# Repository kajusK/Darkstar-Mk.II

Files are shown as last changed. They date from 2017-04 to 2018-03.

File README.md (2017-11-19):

DarkStar Mk.II
==============

Small lightweight, water/mud/shock/bomb proof headlamp with bat roasting
light output and Scurion like body for 1/8 of the price. If you are caver,
mine explorer, biker, etc. with hacker soul, this is a way to go!

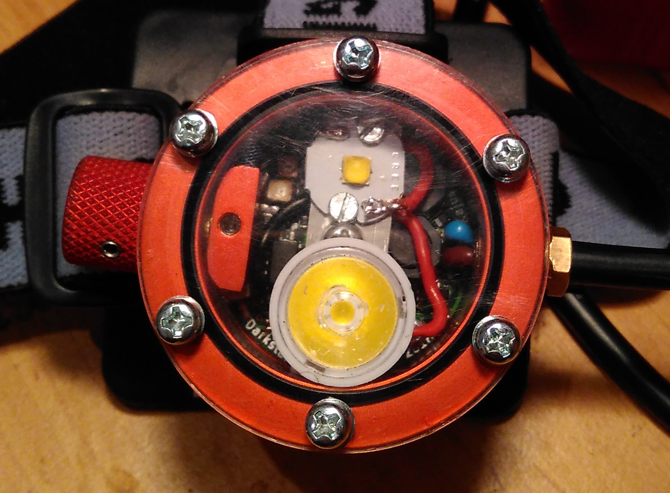
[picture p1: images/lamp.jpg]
Darkstar Mk.II


Features
--------
* Two high power high efficiency XP-L2 LEDs and two low power (e.g. red + UV).
* Up to 869 ANSI lumens (with 80 CRI 4000 K LEDs).
* Anodized aluminium alloy body.
* 3D printed battery box.
* Waterproof up to 2 (tested) meters (IPx8).
* 2 meter drop resistance tested
* Works in wide temperature range - minus 20 °C to plus 60 °C
* Custom high efficiency LED drivers - up to 96 %.
* Up to 2 Amps per LED.
* Runs on single Li-Ion cell, two are recommended for higher run times.
* Thoroughly tested - see [Measurements](./Measurements.md) for more details.
* Simple API for writing custom user modes.
* Temperature and voltage limits to avoid sudden power off or overheating.
* Long run time (over 30 days on lowest mode, over 1,5 hour on full power - for two 3400 mAh cells).
* Low power off current (27 uA), no need to unplug battery after use.
* Easily replaceable LEDs.
* Weights only 277 grams with two 18650 cells.
* Automated light control based on amount of reflected light (EXPERIMENTAL).
* Custom li-ion protection circuit - up to 7 Amps.

Submerged

Weight
------
* Lamp: 92 g
* Battery box: 50 g
* 2x18650 battery pack: 97 g
* Head strap: 38 g

HowTo
=====
Directories
-----------
* **avr** Source code and hex files for AVR
* **pcb** circuit diagrams, PCBs, gerber files and BOM for electrical parts
* **mechanical** Mechanical BOM, drawings, STLs

Electronics
-----------
The LED drivers were custom designed from elementary components, no integrated
LED solution was used. It's based on hystersis driven buck converter with current
feedback.

The current is sensed by 0,056 ohm resistor, voltage across this resistor is
amplified by opamp and fed to the comparator. The comparator is a brain of the
driver. When the measured voltage is higher than reference voltage generated by
MCU, comparator turns the MOSFET off, current drops below hystersis, MOSFET is turned on
and the cycle repeats. Nothing fancy, but quite simple and cheap.
Only few parts are required and measured efficiency is reaching 96 %. Over 90 \% for
currents over 0,5 A for whole supply voltage range allowed.
Check [Measurement](./Measurements.md) for more details.
The maximal current allowed is 2 Amps. It should be possible to get much higher
currents by choosing better (bigger and more expensice) inductors and transistors.

Disadvantage of such design is a limited lowest possible current, it can't go
below half of the hystersis current. For this reason 10-100 % output is constant
current driven, 0-10 % is controlled by additional PWM.

Software
--------

The brain of the lamp is Attiny 841, it handles key presses, reference voltage
generating, etc. To make it simpler to program I use optiboot arduino compatible
bootloader though there is no arduino code included in the project except
the bootloader itself.

To make it simpler to write your own control modes, most of the code is just a library
controlling the hardware and providing few quite low level functions to user. It
takes care of reading buttons, generating reference voltages for LED drivers, etc.

It also contains automated light control (PI regulator). The light is measured
by phototransistor and the difference between the measured value and value
required is run through the PI regulator. Result is the applied to reference
voltage generator. This feature is quite EXPERIMENTAL and doesn't work
well for caving when the lamps gets covered in mud.

The rest is the user mode. Check [simple mode](./avr/src/modes/simple.c) to see
how simple it can get. All relevant header are included. See [HowTo](./HowTo.md)
for more details on programming and stuff.

The caving mode controls are described in [User guide](./User_guide.md).

Mechanical
----------
The body is machined on a lathe from 6063 aluminium alloy. No fancy expensive
tools except lathe and drill press are required to make the lamp.

Top cover is made from polycarbonate sheet, cable and control rods bushings are
made from brass. The whole thing is sealed with O-rings. See the [BOM](./mechanical/BOM.md)
for more details.

The battery box is designed to be printed on any 3D printer. I would suggest
using ABS and painting the resulting print with ABS juice to get is as
waterproof as possible.

Lenses
------
the wide beam led can be used without lenses, the beam is wide enough for my
needs, for the narrow beam led you can buy any compatible lens that fits inside
the body. I used [17mm 10deg lens]
(http://www.aliexpress.com/item/free-shipping-cree-xp-g-lens-diameter-17mm-smooth-surface-with-stand-condenser-lenses-10-deg/777222733.html)

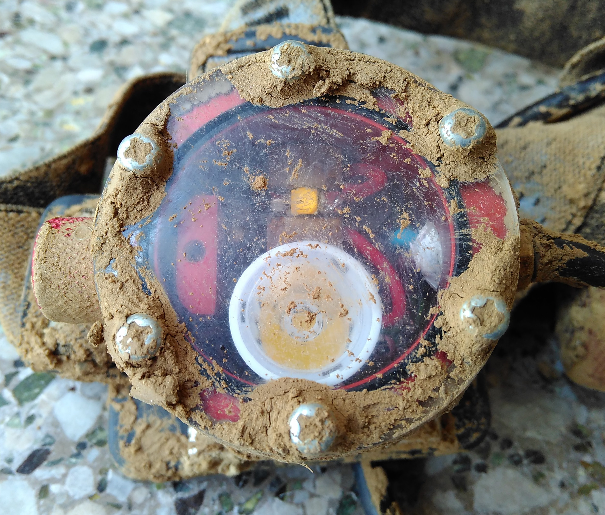
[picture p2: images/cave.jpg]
Cave usage


License
=======

The source code is licenced under [GNU GPL v2](./avr/LICENSE). The mechanical and
electrical design is licensed under [CERN OHL v.1.2](LICENSE).

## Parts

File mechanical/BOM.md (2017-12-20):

Bill Of Material
================

Mechanical only, for electronics see [headlamp BOM](../pcb/headlamp/BOM.csv)
and [li-ion protection BOM](../pcb/liion_protection/BOM.csv).

| Item					| Amount|
|---|---|
| Aluminium 6082 T6, rod, diameter 50	| 25 mm	|
| Aluminium 6082 T6, rod, diameter 15	| 45 mm	|
| Brass, hexagon rod, M11		| 20 mm	|
| Brass, hexagon rod, M8		| 20 mm	|
| Polycarbonate (lexan), 50x50x2 plate	| 1	|
| Screw M3x40, hex head			| 2	|
| Screw M3x5, phillips button head	| 7	|
| Screw M2x5, phillips button head	| 2	|
| Knurled nut M3 inserts		| 2	|
| Set screw M3x4			| 2	|
| O-ring 36x1,5				| 1	|
| O-ring 35x1,5				| 1	|
| O-ring 2x1,5				| 1	|
| Some ABS to print battery box		| 1	|
| 17mm condenser lens 10 deg for XP-L2	| 1	|

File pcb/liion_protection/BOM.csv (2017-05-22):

Reference | Value | Footprint | URL
Q2 | CSD16406Q3 | Housings_SON:VSON-8_3.3x3.3mm_Pitch0.65mm_NexFET | http://cz.mouser.com/search/ProductDetail.aspx?R=0virtualkey0virtualkeyCSD16406Q3
Q1 | CSD16406Q3 | Housings_SON:VSON-8_3.3x3.3mm_Pitch0.65mm_NexFET | http://cz.mouser.com/search/ProductDetail.aspx?R=0virtualkey0virtualkeyCSD16406Q3
R2 | 2k2 | Resistors_SMD:R_0603
R1 | 330R | Resistors_SMD:R_0603
C1 | 100n | Capacitors_SMD:C_0603
U1 | BQ29700DSER | Housings_SON:WSON6_1.5x1.5mm_Pitch0.5mm | http://cz.mouser.com/search/ProductDetail.aspx?R=0virtualkey0virtualkeyBQ29700DSER

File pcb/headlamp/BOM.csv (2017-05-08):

Reference | Value | Footprint | URL
C1 | 10u | Capacitors_SMD:C_0603
C10 | 10n | Capacitors_SMD:C_0603
C2 | 1u | Capacitors_SMD:C_0603
C4 | 1u | Capacitors_SMD:C_0603
C5 | 10n | Capacitors_SMD:C_0603
C6 | 1u | Capacitors_SMD:C_0603
C7 | 1u | Capacitors_SMD:C_0603
C8 | 1u | Capacitors_SMD:C_0603
C9 | 10n | Capacitors_SMD:C_0603
D2 | RED | LEDs:LED_PLCC-2 | http://cz.farnell.com/osram/lr-t67f-u1aa-1/led-smd-plcc2-red/dp/2113954
D3 | WHITE | LEDs:LED_PLCC-2 | http://cz.farnell.com/broadcom-limited/asmt-uwb1-nx3e2/led-smd-plcc2-neutral-white-4500k/dp/1895842
D4 | BAT60AE6327HTSA1 | Diodes_SMD:SOD-323 | http://cz.farnell.com/infineon/bat-60a-e6327/rectifier-schottky-3a-10v-sod/dp/2432679
D5 | BAT60AE6327HTSA1 | Diodes_SMD:SOD-323 | http://cz.farnell.com/infineon/bat-60a-e6327/rectifier-schottky-3a-10v-sod/dp/2432679
D6 | CREE XP-L2 |  | http://cz.mouser.com/ProductDetail/Cree-Inc/XPLBWT-00-0000-000HV340G/
D7 | CREE XP-L2 |  | http://cz.mouser.com/ProductDetail/Cree-Inc/XPLBWT-00-0000-000HV340G/
IC1 | ATTINY841-SSU | Housings_SOIC:SOIC-14_3.9x8.7mm_Pitch1.27mm | http://cz.farnell.com/atmel/attiny841-ssur/mcu-8bit-attiny-16mhz-wsoic-14/dp/2443189
L1 | 10u | Inductors:Inductor_Bourns-SRU8043 | http://cz.farnell.com/bourns/sru8043-100y/choke-power-shielded-10uh/dp/1362119
L2 | 10u | Inductors:Inductor_Bourns-SRU8043 | http://cz.farnell.com/bourns/sru8043-100y/choke-power-shielded-10uh/dp/1362119
Q1 | VEMT3700-GS08 | LEDs:LED_PLCC-2 | http://cz.farnell.com/vishay/vemt3700-gs08/photo-transistor-npn-850nm-plcc/dp/2504152
Q2 | NX2301P | TO_SOT_Packages_SMD:SOT-23 | http://cz.farnell.com/nxp/nx2301p/mosfet-p-ch-20v-2a-sot23/dp/1894738
Q3 | DMP2035U | TO_SOT_Packages_SMD:SOT-23 | http://cz.farnell.com/diodes-inc/dmp2035u/mosfet-p-ch-esd-20v-3-6a-sot23/dp/2061419
Q4 | DMP2035U | TO_SOT_Packages_SMD:SOT-23 | http://cz.farnell.com/diodes-inc/dmp2035u/mosfet-p-ch-esd-20v-3-6a-sot23/dp/2061419
R1 | 8k2 | Resistors_SMD:R_0603
R10 | 220R | Resistors_SMD:R_0603
R11 | 220R | Resistors_SMD:R_0603
R12 | 10k | Resistors_SMD:R_0603
R13 | 10k | Resistors_SMD:R_0603
R14 | 0R056 | Resistors_SMD:R_1206 | http://cz.farnell.com/te-connectivity/rlp73n2br056jtd/resistor-r056-300ppm-0-5w/dp/2116422
R15 | 0R056 | Resistors_SMD:R_1206 | http://cz.farnell.com/te-connectivity/rlp73n2br056jtd/resistor-r056-300ppm-0-5w/dp/2116422
R16 | 1k | Resistors_SMD:R_0603
R17 | 1k | Resistors_SMD:R_0603
R18 | 18k | Resistors_SMD:R_0603
R19 | 18k | Resistors_SMD:R_0603
R2 | 10k | Resistors_SMD:R_0603
R20 | 12k | Resistors_SMD:R_0603
R21 | 12k | Resistors_SMD:R_0603
R22 | 270k | Resistors_SMD:R_0603
R23 | 270k | Resistors_SMD:R_0603
R24 | 1k | Resistors_SMD:R_0603
R25 | 1k | Resistors_SMD:R_0603
R26 | 33R | Resistors_SMD:R_0603
R3 | 10k | Resistors_SMD:R_0603
R4 | 220R | Resistors_SMD:R_0603
R5 | 10k | Resistors_SMD:R_0603
R6 | 10k | Resistors_SMD:R_0603
R7 | 8k2 | Resistors_SMD:R_0603
R8 | 10k | Resistors_SMD:R_0603
R9 | 10k | Resistors_SMD:R_0603
SW1 | BT2 | Buttons_Switches_SMD:SW_SPST_FSMSM | http://cz.farnell.com/alcoswitch-te-connectivity/1437566-3/pushbutton-switch-spst-0-05a-24v/dp/2468741
SW2 | BT1 | Buttons_Switches_SMD:SW_SPST_FSMSM | http://cz.farnell.com/alcoswitch-te-connectivity/1437566-3/pushbutton-switch-spst-0-05a-24v/dp/2468741
U1 | ZXGD3001E6 | TO_SOT_Packages_SMD:SOT-23-6 | http://cz.farnell.com/diodes-inc/zxgd3001e6ta/driver-gate-bipolor-9a-peak/dp/1549138
U2 | ZXGD3001E6 | TO_SOT_Packages_SMD:SOT-23-6 | http://cz.farnell.com/diodes-inc/zxgd3001e6ta/driver-gate-bipolor-9a-peak/dp/1549138
U3 | TSV912 | Housings_SSOP:MSOP-8_3x3mm_Pitch0.65mm | http://cz.farnell.com/stmicroelectronics/tsv912aiyst/op-amp-rrio-8mhz-4-5v-s-8/dp/1842603
U4 | MCP6567 | Housings_SSOP:MSOP-8_3x3mm_Pitch0.65mm | http://cz.farnell.com/microchip/mcp6567-e-ms/ic-comparator-dual-1-8v-8msop/dp/1834862

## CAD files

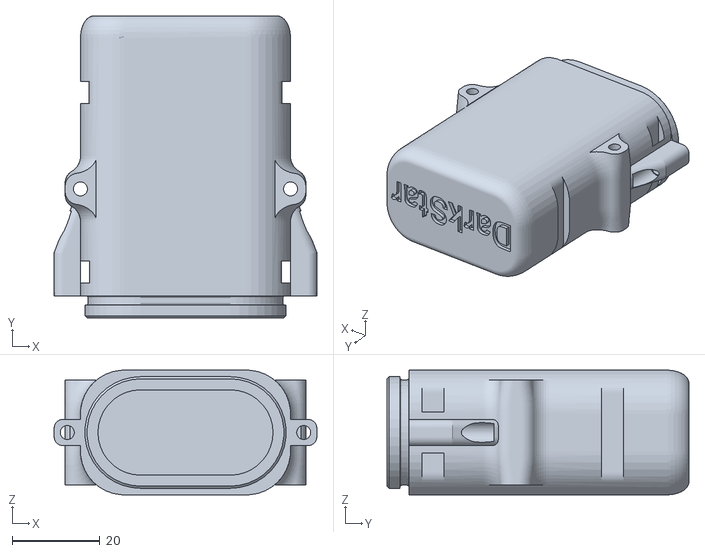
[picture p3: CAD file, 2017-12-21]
mechanical/stl/battery_box.stl
60.0 x 69.0 x 28.5

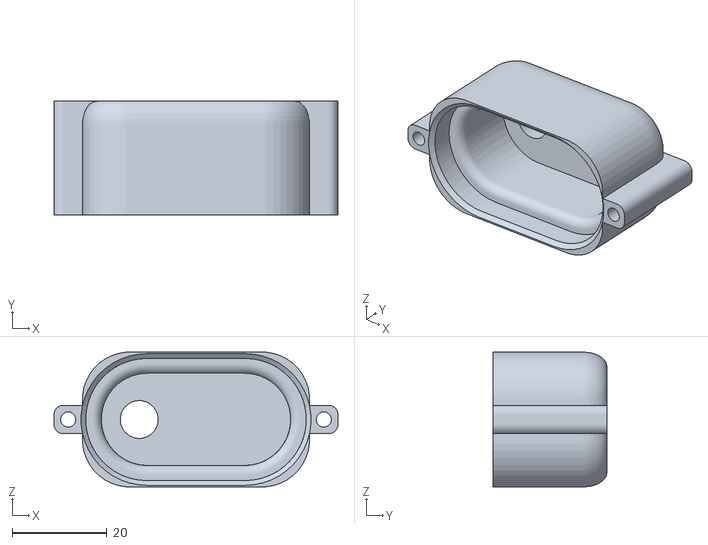
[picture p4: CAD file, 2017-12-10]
mechanical/stl/box_lid.stl
60.0 x 24.0 x 28.5

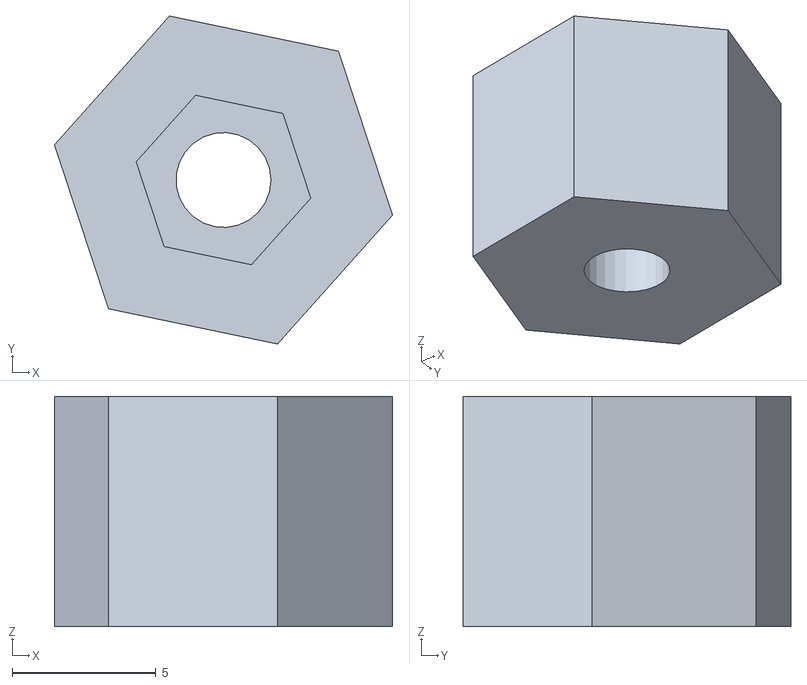
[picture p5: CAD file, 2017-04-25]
mechanical/stl/knob.stl
11.7 x 11.4 x 8.00

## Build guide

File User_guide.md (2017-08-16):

User guide
==========

Darkstar Mk.II light has four (one optional) sources of light:

- High power spot LED
- High power flood LED
- Low power red LED
- Low power white LED (optional)

The lamp is powered by 3,7 V Li-Ion rechargeable battery. Alternative power sources
are possible, voltage of such source must fall between 3 and 5 V.
Maximal worst condition current drawn is 4 A.

The lamp itself and battery box were designed for wet caves and harsh environment.
No drying is required after immersion in water. Cleaning can be done simply by
washing the whole lamp in water. Watertightness can be guaranteed only when
sealing O-rings are clean and lubricated properly though.

Programming
===========
There are two ways to update firmware. The hard one is using AVR ISP programmer,
soldering 6 wires to PCB (or using pogo pins). Simpler way is using bootloader
(if it was uploaded already). The darkstar Mk.II is using standard optiboot
bootloader compatible with arduino IDE.

See [HowTo](./HowTo.md).

Modes
=====
Caving firmware
---------------
While using caving mode firmware, the lamp can be in one of three modes:

- Normal
- Programming
- Configuration

### Normal mode

In normal mode, short button presses are changing brightness of all LEDs
based on the programmed levels. Long press of Down button while LEDs are
on will turn the headlamp off. If Up button is hold, programming mode is entered.
It's signalized by 1 blink.

If lamp is off and Down button is hold, the lock mode is activated. To disable
lock mode, just briefly push Up and Down buttons several times. If up button
is hold in off state, current battery level is reported by 1 (low) to 5 (full)
blinks.

Additionally, when the battery drops to ~50 %, it's signalized by one blink.
Low battery is 3 blinks. Something in the middle is signalized by 2 blinks. After
the blinking is finished, output power is limited by amount based on remaining
charge. Output power can be also limited when body temperature limit is reached.

### Programming mode

In this mode, current level selected can be changed for each LED. Up button
cycles SPOT LED levels, Down is for FLOOD. Holding Down toggles RED LED, holding
up toggles WHITE LED.

Programming mode is left automatically after 2,5 seconds of inactivity. Return
is followed by 1 slow blink.

### Configuration mode

Configuration mode is entered by holding Down button while connecting batteries.
Once in configuration mode, the red LED is on.

Up/Down buttons change number of modes available in normal mode. Long Down press
will blink out number of modes enabled.

Long Up press enables/disables programming mode. Enabled programming is confirmed by
two fast blinks. Disabled by one.

After the configuration is finished, wait for 2 seconds, disconnect the battery
and connect it again.

Simple firmware
---------------
Quite simple firmware with almost no features. It's more like technology
demonstration.

Holding DOWN button toggles RED LED. Holding UP button powers the headlamp
on and off. Short Up press cycles through spot LED power levels, Down press
changes flood LED output power.

There's no warning about battery state and heat/voltage limits are only for
the critical values (extra hot and almost dead battery). It won't let you in
the darkness immediately though, the hardcoded limits set output to minimum first.

Safety
======

- Always carry a second, independent source of light during your caving trip!

- Laser class 2 device. Do not look directly into the light.

- Keep the lamp and batteries away from children.

- Never short or mechanically damage the batteries, Li-Ion cell might catch fire or explode

- Never left batteries connected to charger without supervision

- When using alternate batteries, make sure the voltage applied and polarity is correct

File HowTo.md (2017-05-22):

Howto
=====

Writing custom mode
-------------------
When the mcu is powered on, it initializes itself and run init(). This function
has to be implemented in user mode and must return.

Then the infinite loop is entered. In the loop, library reads buttons, sets the
PWM generators, and runs loop() function from user mode. The loop() must return
withing 10ms and cannot be blocking.

For example how to write custom modes browse the [simple mode](./avr/src/modes/simple.c)
and api headers [system.h](./avr/src/library/system.h), [buttons.h](./avr/src/library/buttons.h)
and [light.h](./avr/src/library/light.h).

Compilation
-----------
To compile specific mode, just run

```
make MODE=modename
```

where modename is e.g. ***simple*** or ***caving***

MCU programming
---------------
Due to limited space, there is no dedicated programming connector on the PCB.
To burn the bootloader, you'll need program the MCU before soldering or
solder programmer wires directly to mcu pins or make custom programming head
using pogo pins.

The [optioboot](https://github.com/SpenceKonde/arduino-tiny-841/tree/master/avr/bootloaders/optiboot)
bootloader is recommended way to programm the MCU. The attiny841 has no boot
section, so the optiboot creates virtual boot partition by replacing
first instruction by jump to itself.

To make self programming working, SELFPRGEN fuse needs to be changed, e.g. by command:
```
avrdude -c usbtiny -p attiny841 -U efuse:w:0xFE:m
```

When the bootloader is burned, the MCU can be programmed over serial port.
When using serial interface, use supply voltage below 4 volts. On higher
voltages the internal oscillator runs faster and interferes with baudrate settings.
If you need to use UART on voltages over 4 volts, oscillator calibration might be
needed. The makefile contains programming target, just HW reset the MCU and run:

```
make MODE=modename program
```

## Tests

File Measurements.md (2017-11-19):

Measurements
============

Electrical and heat
-------------------
As the headlamp was build for my bachelor thesis, I went through couple of
measurements of various parameters.

The most important part is the LED driver. Its efficiency and heat management
defines most of the headlamp parameters.

When tested under maximum load - 4,2 V, 2 Amps - the drivers temperature
settles at 67 degrees Celsius.

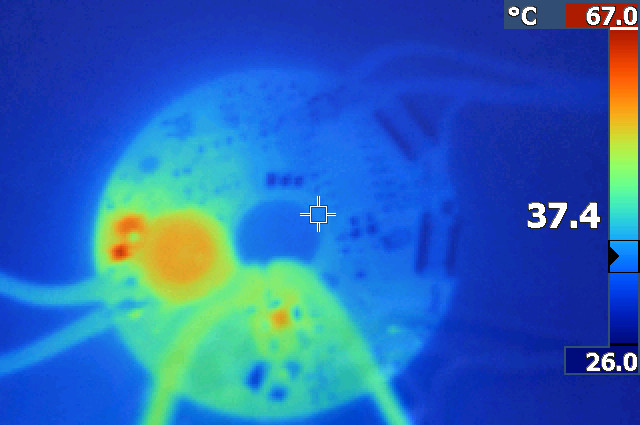
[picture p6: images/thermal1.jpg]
Driver heating


The measured efficiency is over 90 % for currents over 0,5 A over the whole
input voltage range and it's topping on 96,9 %.

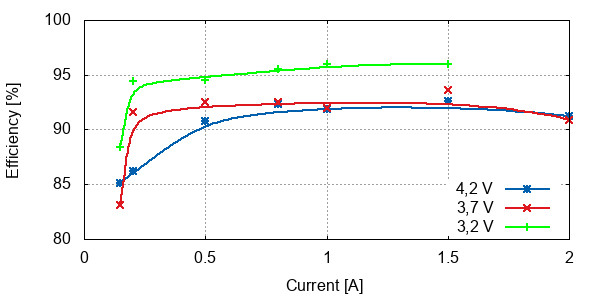
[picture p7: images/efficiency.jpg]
Efficiency


As the buck driver is hystersis driven, the frequency is not stable, but it varies
with input and output voltage significantly.

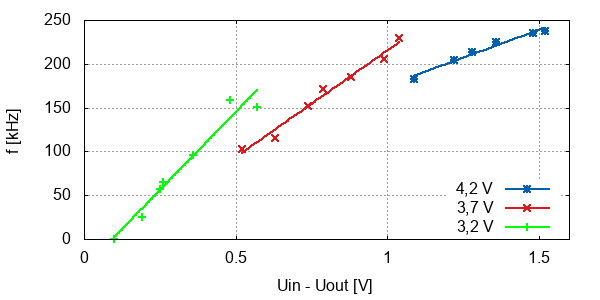
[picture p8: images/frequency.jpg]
Frequency


The driver supply voltage can go as low as 0,1 V over output voltage. 3,2 V battery
can therefore run XP-L2 on 2 Amps without any problem (when ignoring voltage drop
on wires).

As the comparator driving the switching transistor is open drain, there is non
zero current flowing through pull up and feedback resistor to ground when
the lamp is off. The measured power off current is 27 uA for the whole headlamp
with two drivers and MCU in sleep.

As the buck driver is in switching configuration, the current through LED is
not stable, but it's oscillating around the configured value with about
300 mA ripple.

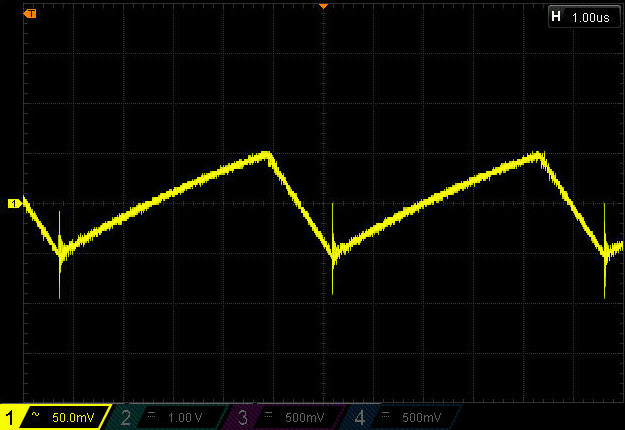
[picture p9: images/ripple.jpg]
Ripple


As there are no ideal components out there, the switching is not as smooth as
it could be. The diode recovery time is non zero and when the switch occurs,
voltage peak appears on the coil. The following image shows the issue (voltage
in the point where transistor, diode and inductor connect together).

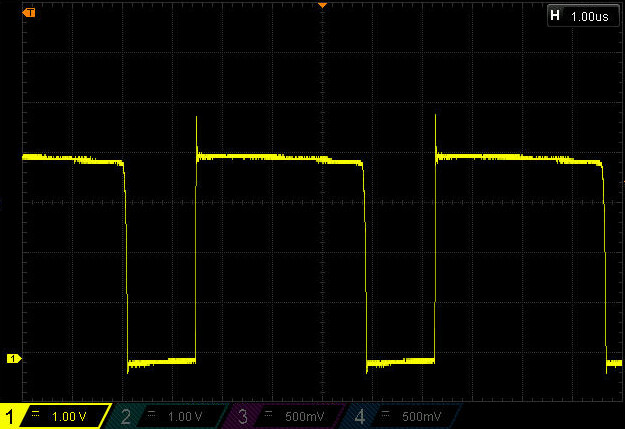
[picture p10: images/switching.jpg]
Switching


These peaks can get to the supply voltage. In the beginning I was using
diode detector to avoid voltage drops on MCU power rail, but the peaks
were slowly charging the capacitor on MCU side, voltage was rising. The result
was voltage break down of the opamp. After replacing the detector with RC
low pass, the problem was fixed.

When the lamp is running on full power, LEDs heat up to about 100 degree Celsius
before the body goes to 60 degrees and the temperature control kicks in.
This could be heavily improved by using cooper heatsink.

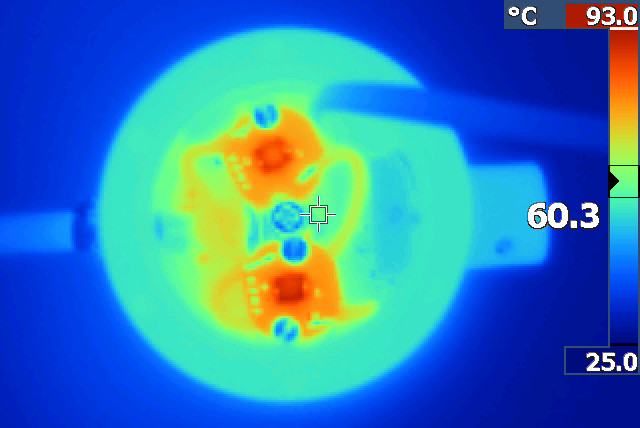
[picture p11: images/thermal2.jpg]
Body


Light
-----
The light was measured in integrating sphere at Faculty of Electrical Engineering
and Communication, Brno University of Technology.

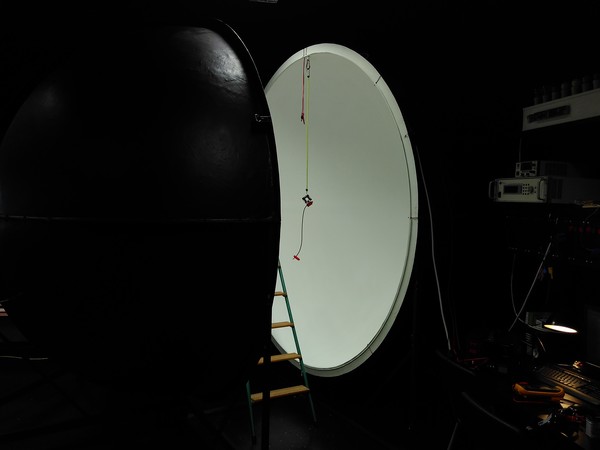
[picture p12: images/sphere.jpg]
Sphere


The measured light spectrum reveals a bit of LED principles. The peak at 450 nm
marks the light of the LED junction, the rest is created by luminophore.

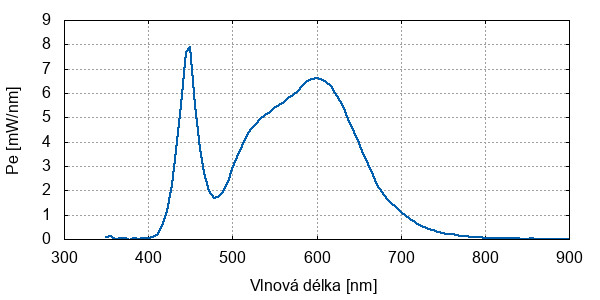
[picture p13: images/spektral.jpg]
Spektral


In the prototype measured, I used XP-L2, 4000K LEDs, one with CRI > 70, second
with CRI > 80.

| Item				| Value			|
|---|---|
| Min luminous flux		| 1,66 lm / 8 mA	|
| Max luminous flux		| 869 lm / 4 A		|
| Average max luminous flux	| 785 lm / 4 A		|
| Colour temperature		| 3937 K		|
| CRI				| 85,7			|

Temperature cycling
-------------------
To test the temperature range the lamp can work in, I put the lamp into the
freezer (-18 °C) for 30 minutes, checked everything works and then moved it into the oven
set to 60 degrees Celsius for 30 minutes and check if it works again.

This was repeated several times. The battery box got a bit soft in the oven.
The cable between the box and the lamp body was pretty hard after taking it out of the
freezer. But these changes were just temporary and everything else worked well.

Impact resistance
-----------------
The light was dropped from height 2 meters 6 times in different orientations on
a concrete floor. In the first set of tests, the optical part of the LED
was cut away by the lens, therefore I glued the lens into place and repeated
the test with a new LED. This time, nothing was damaged, only few scratches appeared
on the lamp surface.

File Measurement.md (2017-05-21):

Measurements
============

Electrical and heat
-------------------
As the headlamp was build for my bachelor thesis, I went through couple of
measurements of various parameters.

The most important part is the LED driver. Its efficiency and heat management
defines most of the headlamp parameters.

When tested under maximum load 4,2 V input, 2 amps load, the driver temperature
settles at 67 degrees Celsius.

Driver heating

The measured efficiency is over 90 % for currents over 0,5 A over the whole
input voltage range and it's topping on 96,9 %.

Efficiency

As the buck driver is hystersis driven, the frequency is not stable, but it varies
with input and output voltage significantly.

Frequency

The driver supply voltage can as low as 0,1 V over output voltage. 3,2 V battery
can therefore run XP-L2 on 2 Amps without any problem (when ignoring voltage drop
on wires).

As the comparator driving the switching transistor is open drain, there is non
zero current flowing through pull up and feedback resistor to ground when
the lamp is off. The measured power off current is 27 uA for the whole headlamp
with two drivers and MCU in sleep.

As the buck driver is in switching configuration, the current through LED is
not stable, but it's oscillating around the configured value with about
300 mA ripple.

Ripple

As there are no ideal components out there, the switching is not as smooth as
it could be. The diode recovery time is non zero and when the switch occurs,
voltage peak appears on the coil. The following image shows the issue (voltage
in the point where transistor, diode and coil connect together).

Switching

These peaks can get to the supply voltage, at the beginning I was using
diode detector to avoid voltage drops on MCU power rail, but the peaks
were slowly charging the capacitor on MCU side, voltage was rising. The result
was voltage break down of the opamp. After replacing the detector with RC
low pass, the problem was fixed.

When the lam is running on full power, LEDs heat up to about 100 degree Celsius
before the body goes to 60 degrees and the temperature control kicks in.
This could be heavily improved by using cooper heatsink.

Body

Light
-----
TODO

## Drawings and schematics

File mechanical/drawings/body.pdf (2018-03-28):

1 | 2 | 3 | 4
A | A

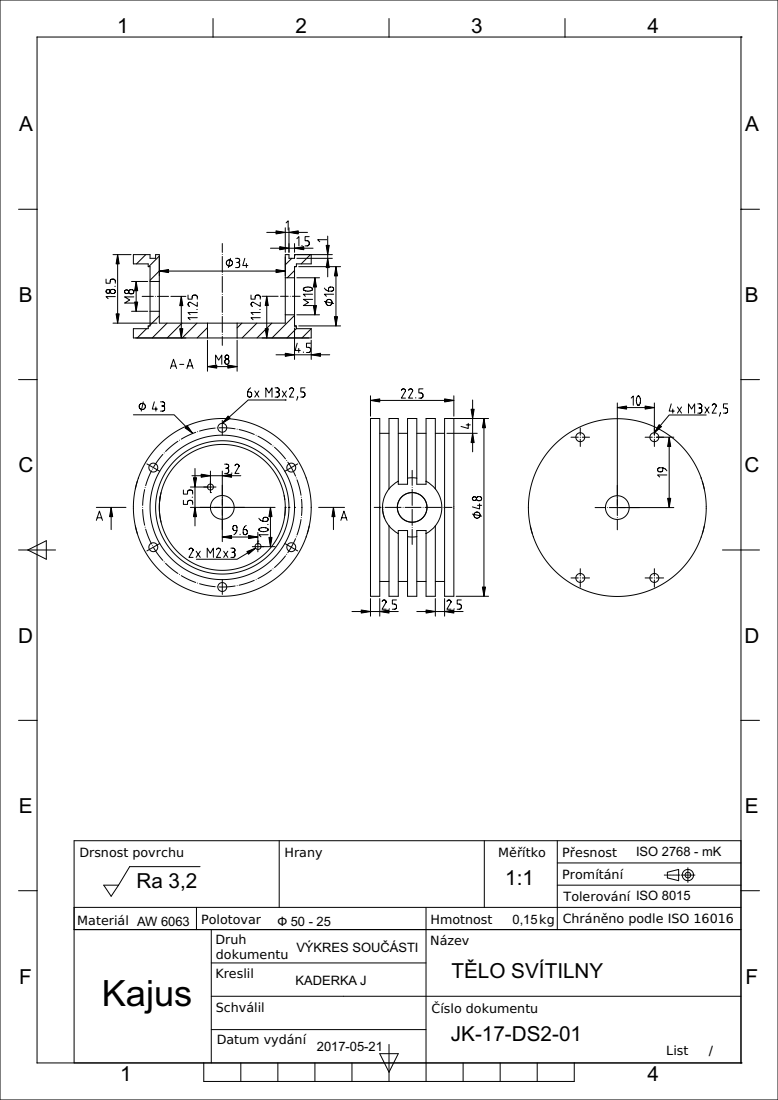
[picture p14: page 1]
Drsnost povrchu; Hrany; Kreslil; Měřítko; Přesnost; Tolerování; Promítání; KADERKA J; ISO 2768 - mK; ISO 8015

Materiál AW 6063 | Polotovar Ф 50 - 25 | Hmotnost 0,15 kg | Chráněno podle ISO 16016
Kajus | Druh VÝKRES SOUČÁSTI dokumentu | Název TĚLO SVÍTILNY

Schválil | Číslo dokumentu JK-17-DS2-01 List /

Datum vydání

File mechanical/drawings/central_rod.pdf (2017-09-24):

1 | 2 | 3 | 4
A | A

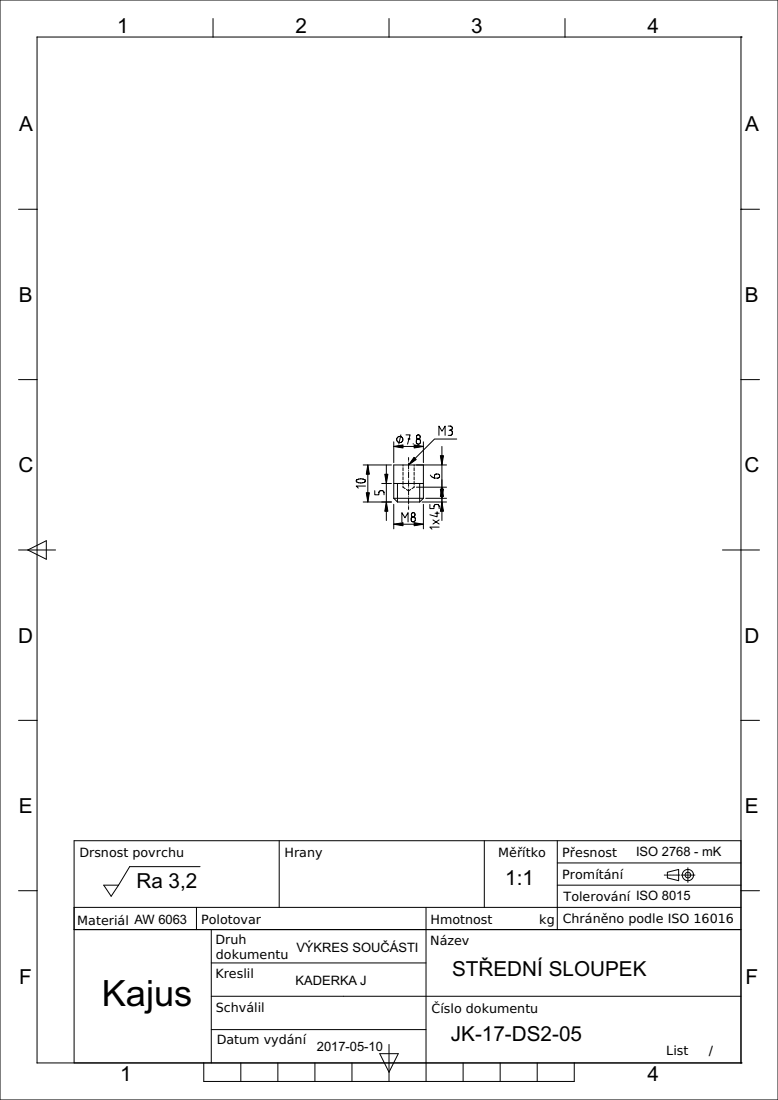
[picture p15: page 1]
Drsnost povrchu; Hrany; Kreslil; Měřítko; Přesnost; Tolerování; Promítání; KADERKA J; ISO 2768 - mK; ISO 8015

Materiál AW 6063 | Polotovar | Hmotnost kg | Chráněno podle ISO 16016
Kajus | Druh VÝKRES SOUČÁSTI dokumentu | Název STŘEDNÍ SLOUPEK

Schválil | Číslo dokumentu JK-17-DS2-05 List /

Datum vydání

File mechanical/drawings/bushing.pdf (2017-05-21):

1 | 2 | 3 | 4
A | A

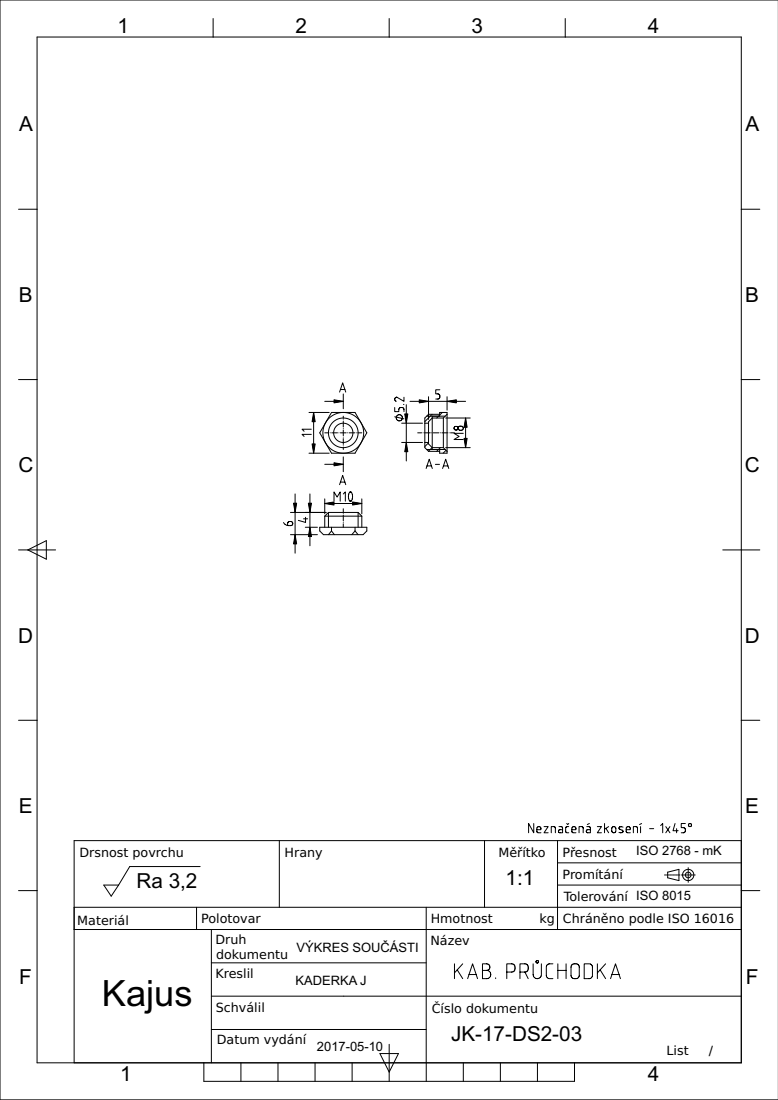
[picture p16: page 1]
Drsnost povrchu; Hrany; Kreslil; Měřítko; Přesnost; Tolerování; Promítání; KADERKA J; ISO 2768 - mK; ISO 8015

Materiál | Polotovar | Hmotnost kg | Chráněno podle ISO 16016
Kajus | Druh VÝKRES SOUČÁSTI dokumentu | Název

Schválil | Číslo dokumentu JK-17-DS2-03 List /

Datum vydání

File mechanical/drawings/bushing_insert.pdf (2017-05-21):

1 | 2 | 3 | 4
A | A

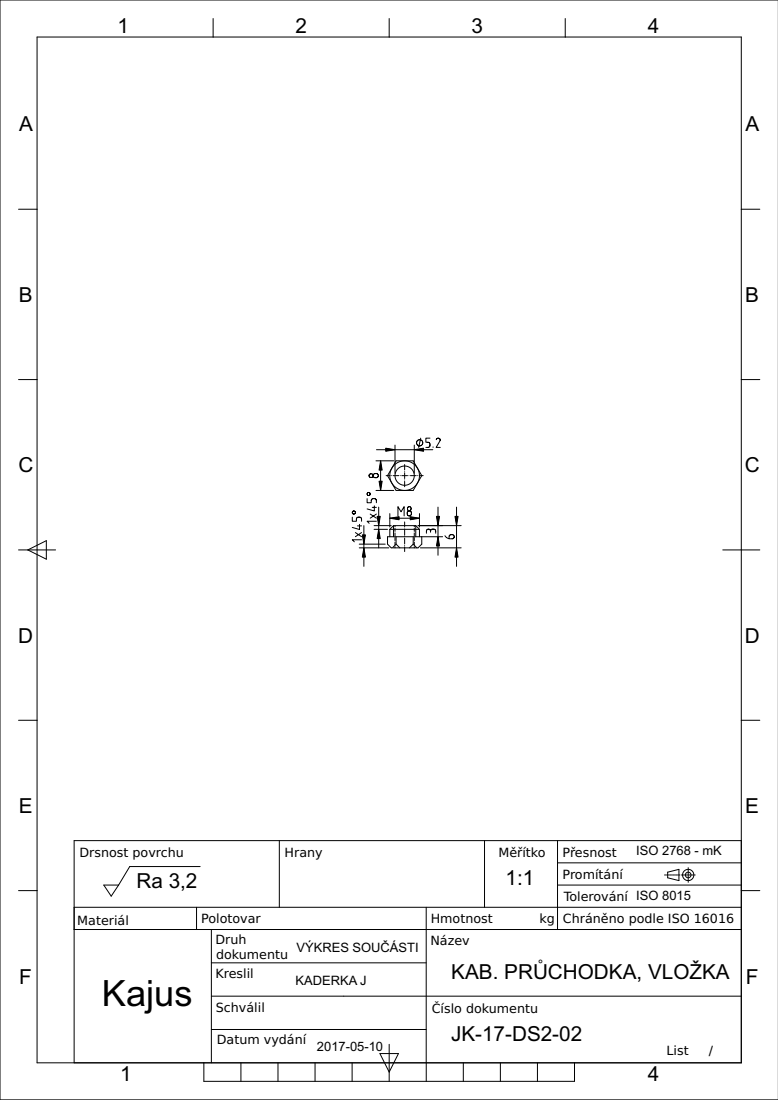
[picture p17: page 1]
Drsnost povrchu; Hrany; Kreslil; Měřítko; Přesnost; Tolerování; Promítání; KADERKA J; ISO 2768 - mK; ISO 8015

Materiál | Polotovar | Hmotnost kg | Chráněno podle ISO 16016
Kajus | Druh VÝKRES SOUČÁSTI dokumentu | Název KAB. PRŮCHODKA, VLOŽKA

Schválil | Číslo dokumentu JK-17-DS2-02 List /

Datum vydání

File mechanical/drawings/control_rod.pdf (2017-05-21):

1 | 2 | 3 | 4
A | A

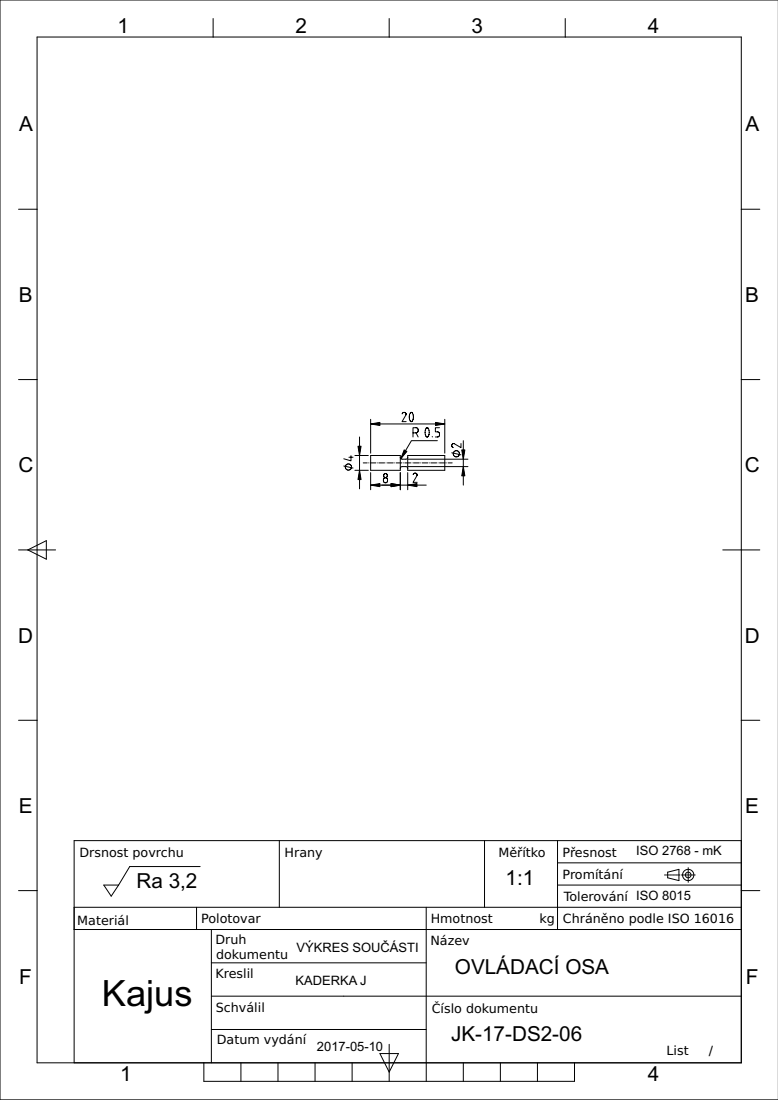
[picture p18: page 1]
Drsnost povrchu; Hrany; Kreslil; Měřítko; Přesnost; Tolerování; Promítání; KADERKA J; ISO 2768 - mK; ISO 8015

Materiál | Polotovar | Hmotnost kg | Chráněno podle ISO 16016
Kajus | Druh VÝKRES SOUČÁSTI dokumentu | Název OVLÁDACÍ OSA

Schválil | Číslo dokumentu JK-17-DS2-06 List /

Datum vydání

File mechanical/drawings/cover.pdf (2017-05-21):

1 | 2 | 3 | 4
A | A

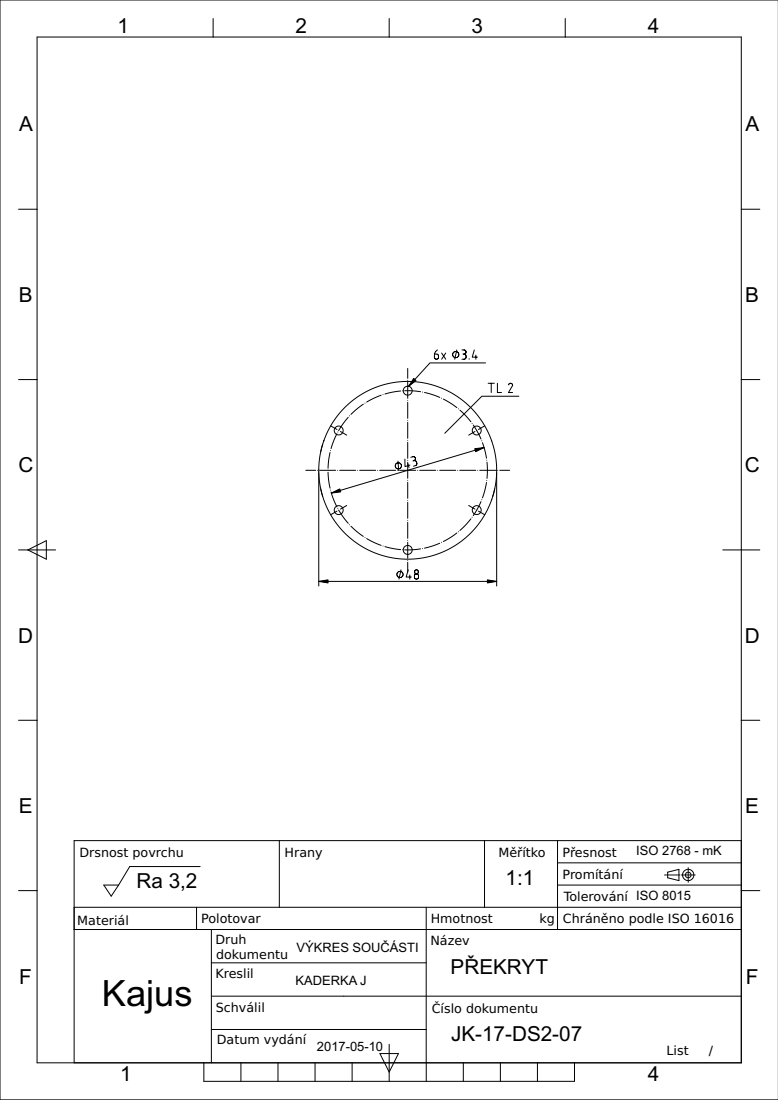
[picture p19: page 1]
Drsnost povrchu; Hrany; Kreslil; Měřítko; Přesnost; Tolerování; Promítání; KADERKA J; ISO 2768 - mK; ISO 8015

Materiál | Polotovar | Hmotnost kg | Chráněno podle ISO 16016
Kajus | Druh VÝKRES SOUČÁSTI dokumentu | Název PŘEKRYT

Schválil | Číslo dokumentu JK-17-DS2-07 List /

Datum vydání

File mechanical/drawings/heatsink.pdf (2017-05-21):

1 | 2 | 3 | 4
A | A

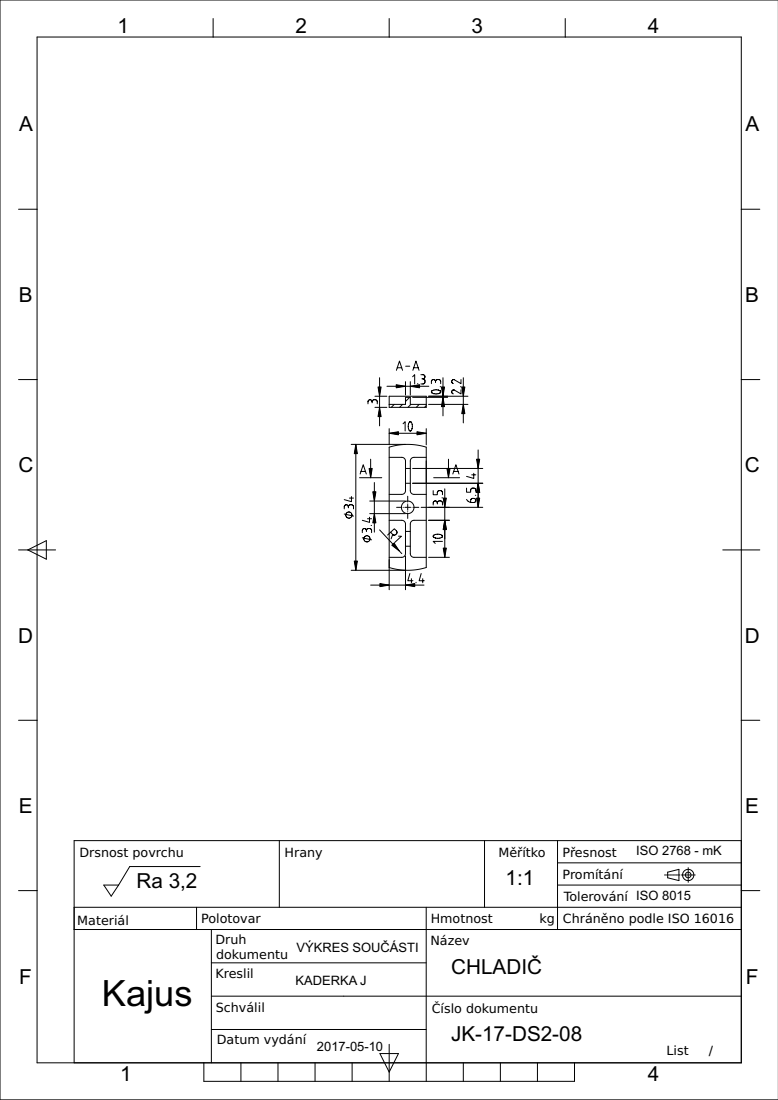
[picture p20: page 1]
Drsnost povrchu; Hrany; Kreslil; Měřítko; Přesnost; Tolerování; Promítání; KADERKA J; ISO 2768 - mK; ISO 8015

Materiál | Polotovar | Hmotnost kg | Chráněno podle ISO 16016
Kajus | Druh VÝKRES SOUČÁSTI dokumentu | Název CHLADIČ

Schválil | Číslo dokumentu JK-17-DS2-08 List /

Datum vydání

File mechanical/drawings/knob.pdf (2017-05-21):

1 | 2 | 3 | 4
A | A

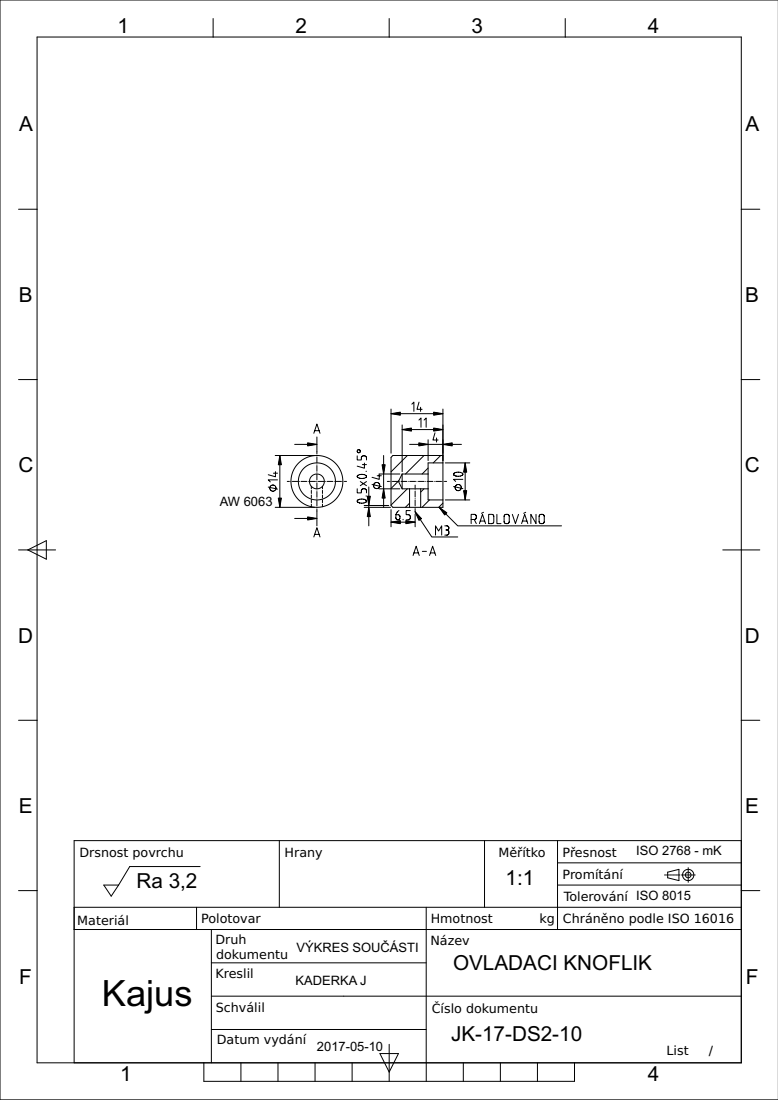
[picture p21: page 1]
Drsnost povrchu; Hrany; Kreslil; Měřítko; Přesnost; Tolerování; Promítání; KADERKA J; ISO 2768 - mK; ISO 8015

Materiál | Polotovar | Hmotnost kg | Chráněno podle ISO 16016
Kajus | Druh VÝKRES SOUČÁSTI dokumentu | Název OVLADACI KNOFLIK

Schválil | Číslo dokumentu JK-17-DS2-10 List /

Datum vydání

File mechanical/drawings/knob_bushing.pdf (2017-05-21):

1 | 2 | 3 | 4
A | A

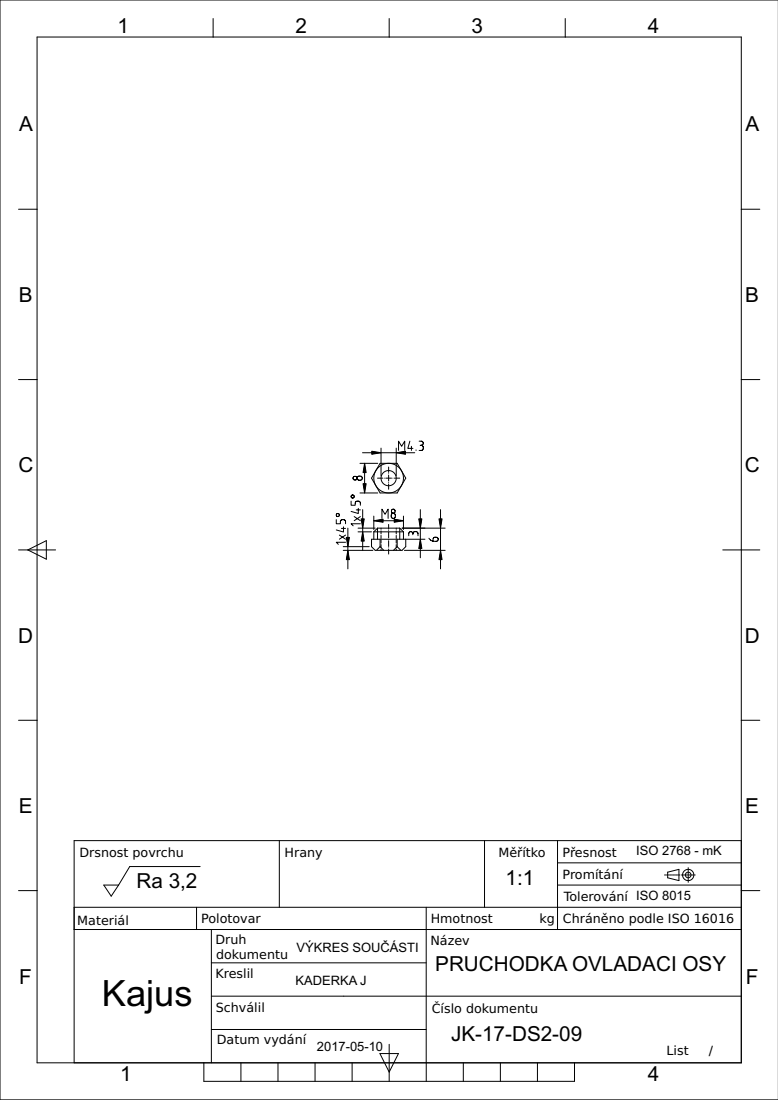
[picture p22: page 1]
Drsnost povrchu; Hrany; Kreslil; Měřítko; Přesnost; Tolerování; Promítání; KADERKA J; ISO 2768 - mK; ISO 8015

Materiál | Polotovar | Hmotnost kg | Chráněno podle ISO 16016
Kajus | Druh VÝKRES SOUČÁSTI dokumentu | Název PRUCHODKA OVLADACI OSY

Schválil | Číslo dokumentu JK-17-DS2-09 List /

Datum vydání

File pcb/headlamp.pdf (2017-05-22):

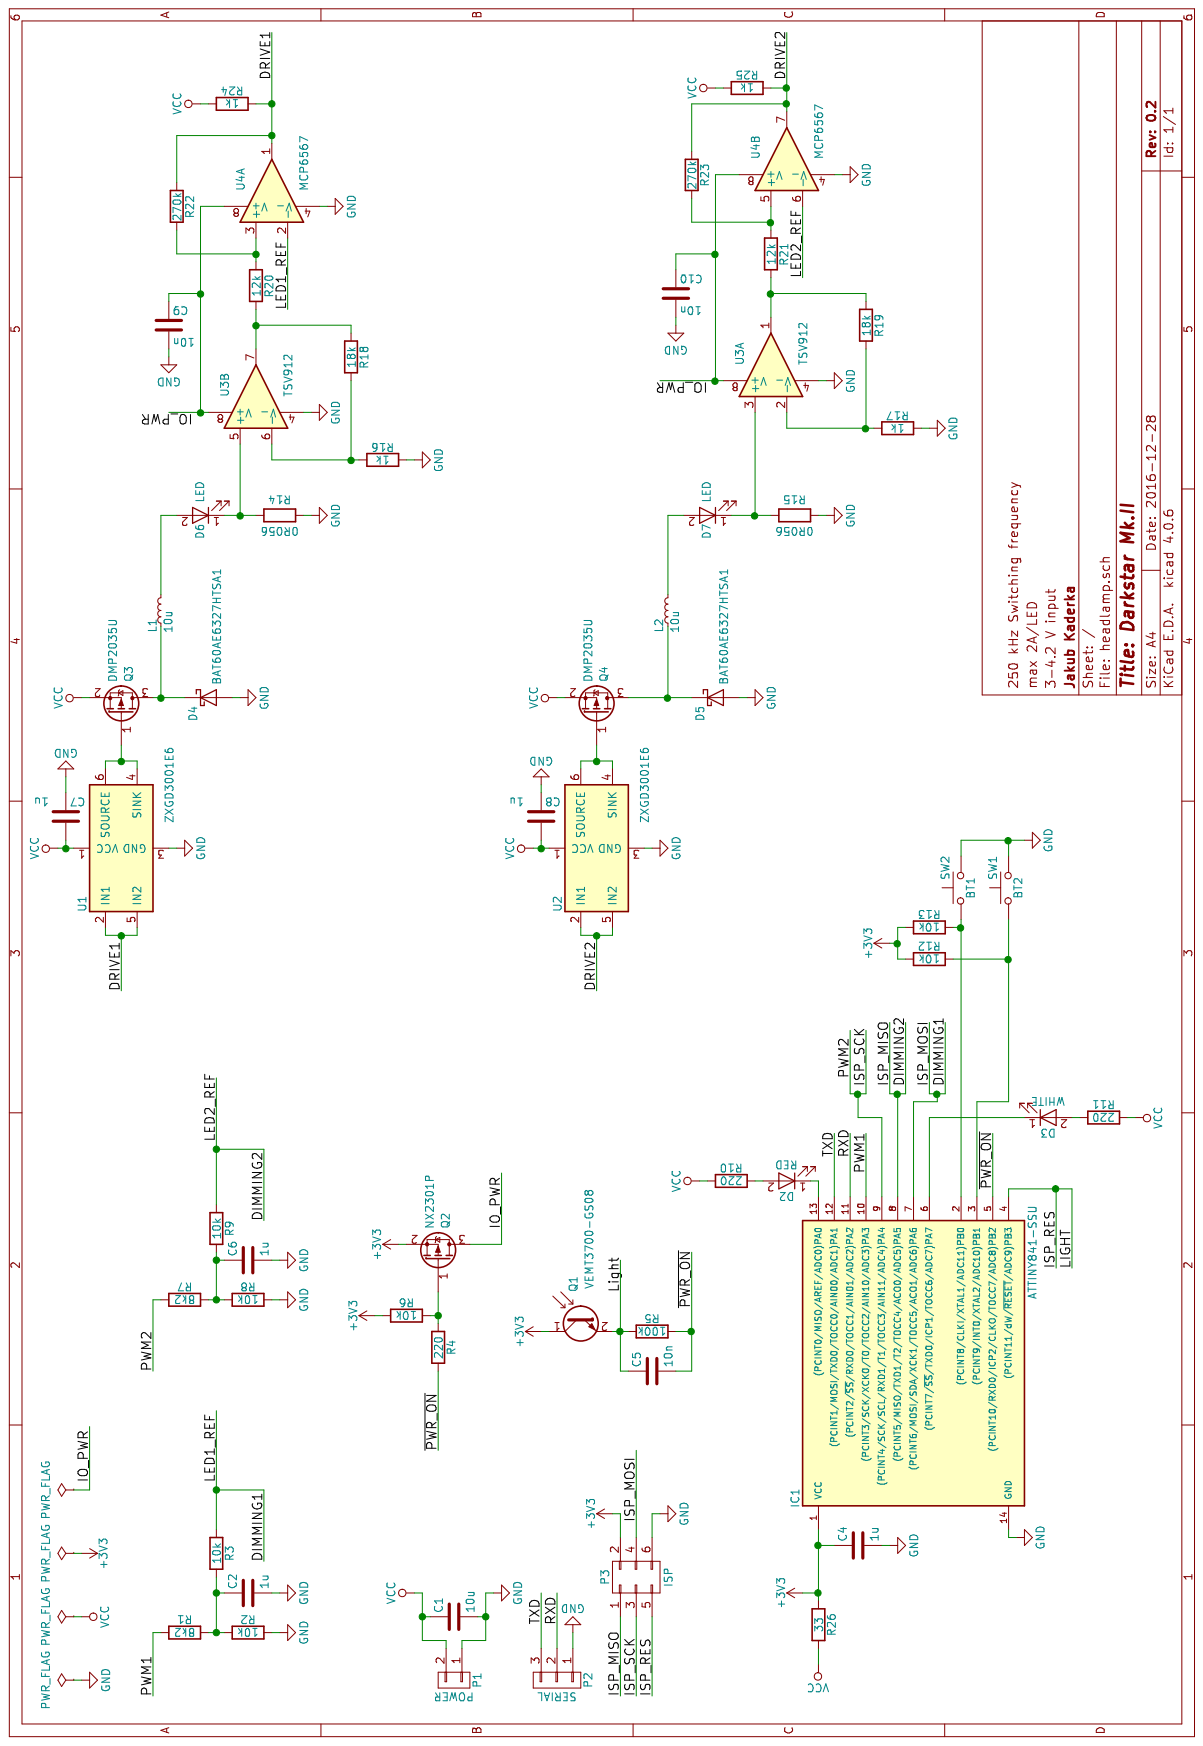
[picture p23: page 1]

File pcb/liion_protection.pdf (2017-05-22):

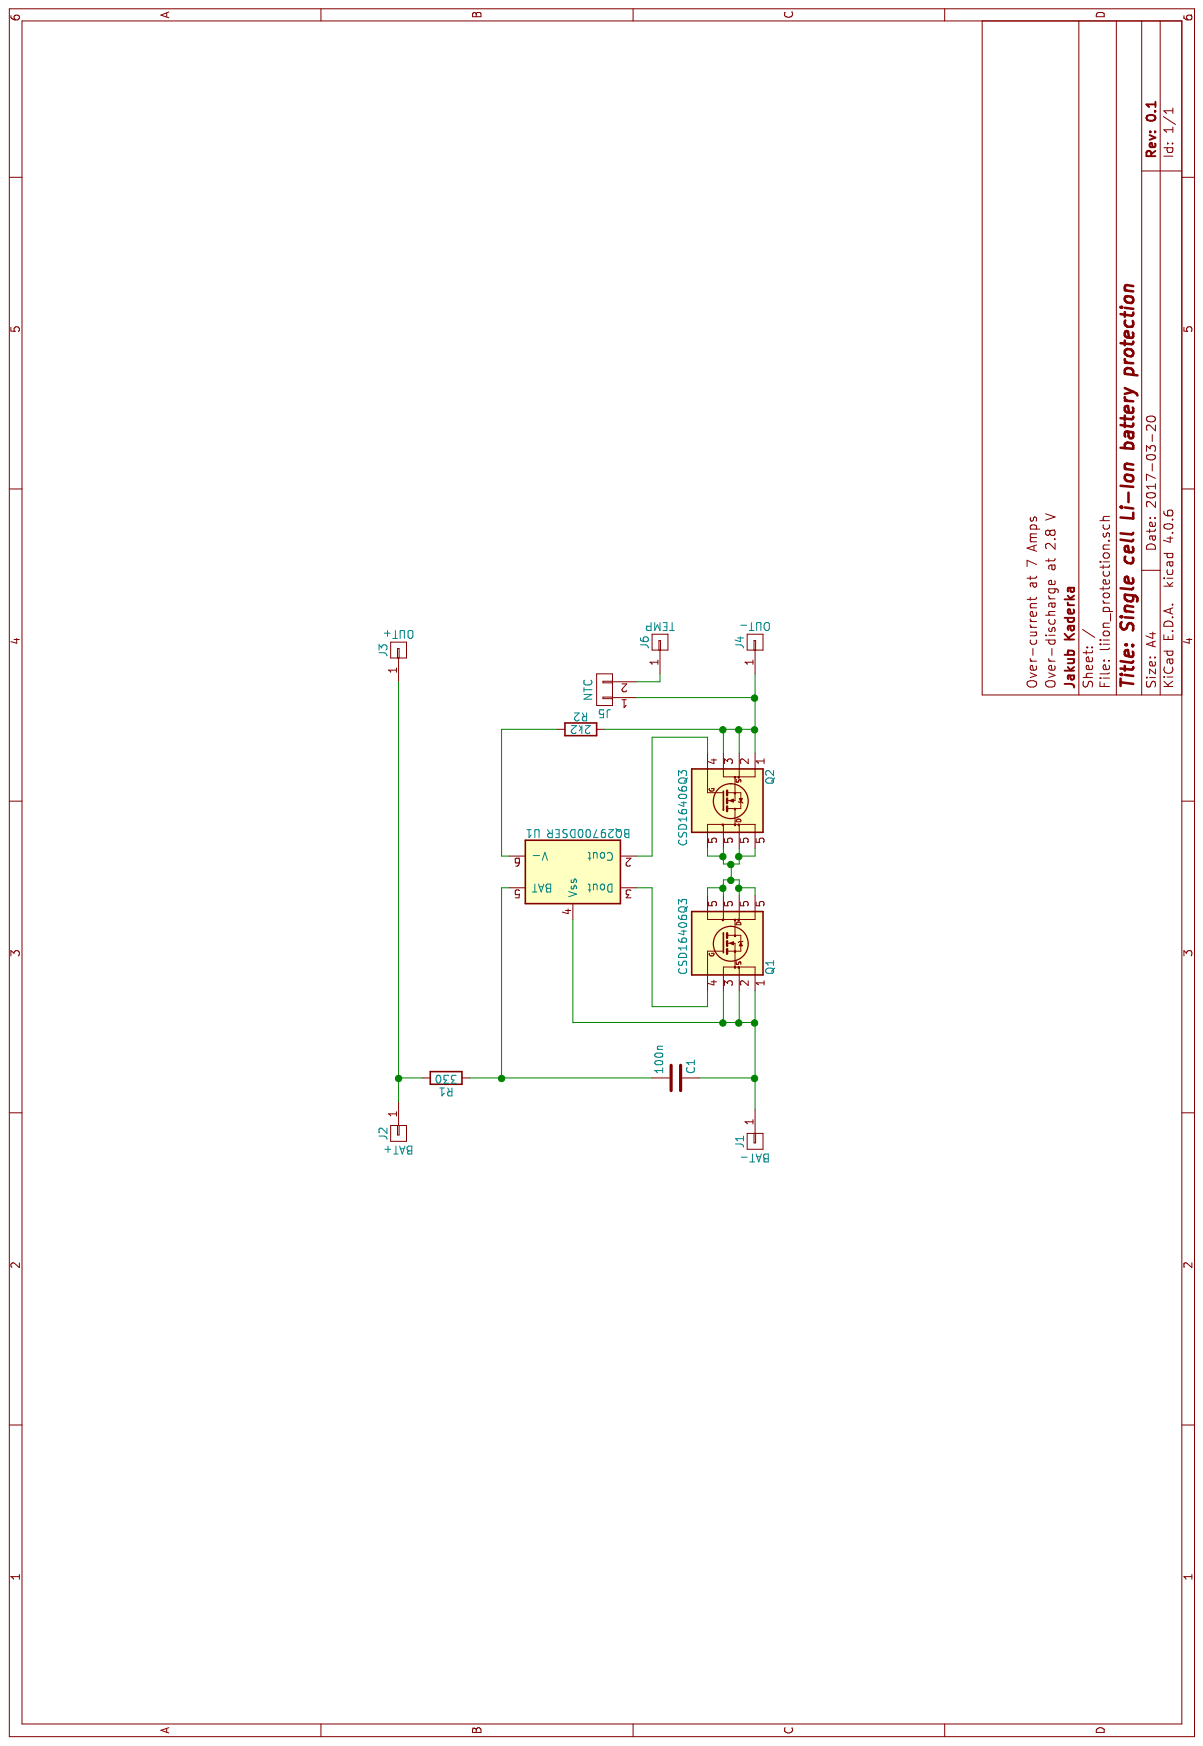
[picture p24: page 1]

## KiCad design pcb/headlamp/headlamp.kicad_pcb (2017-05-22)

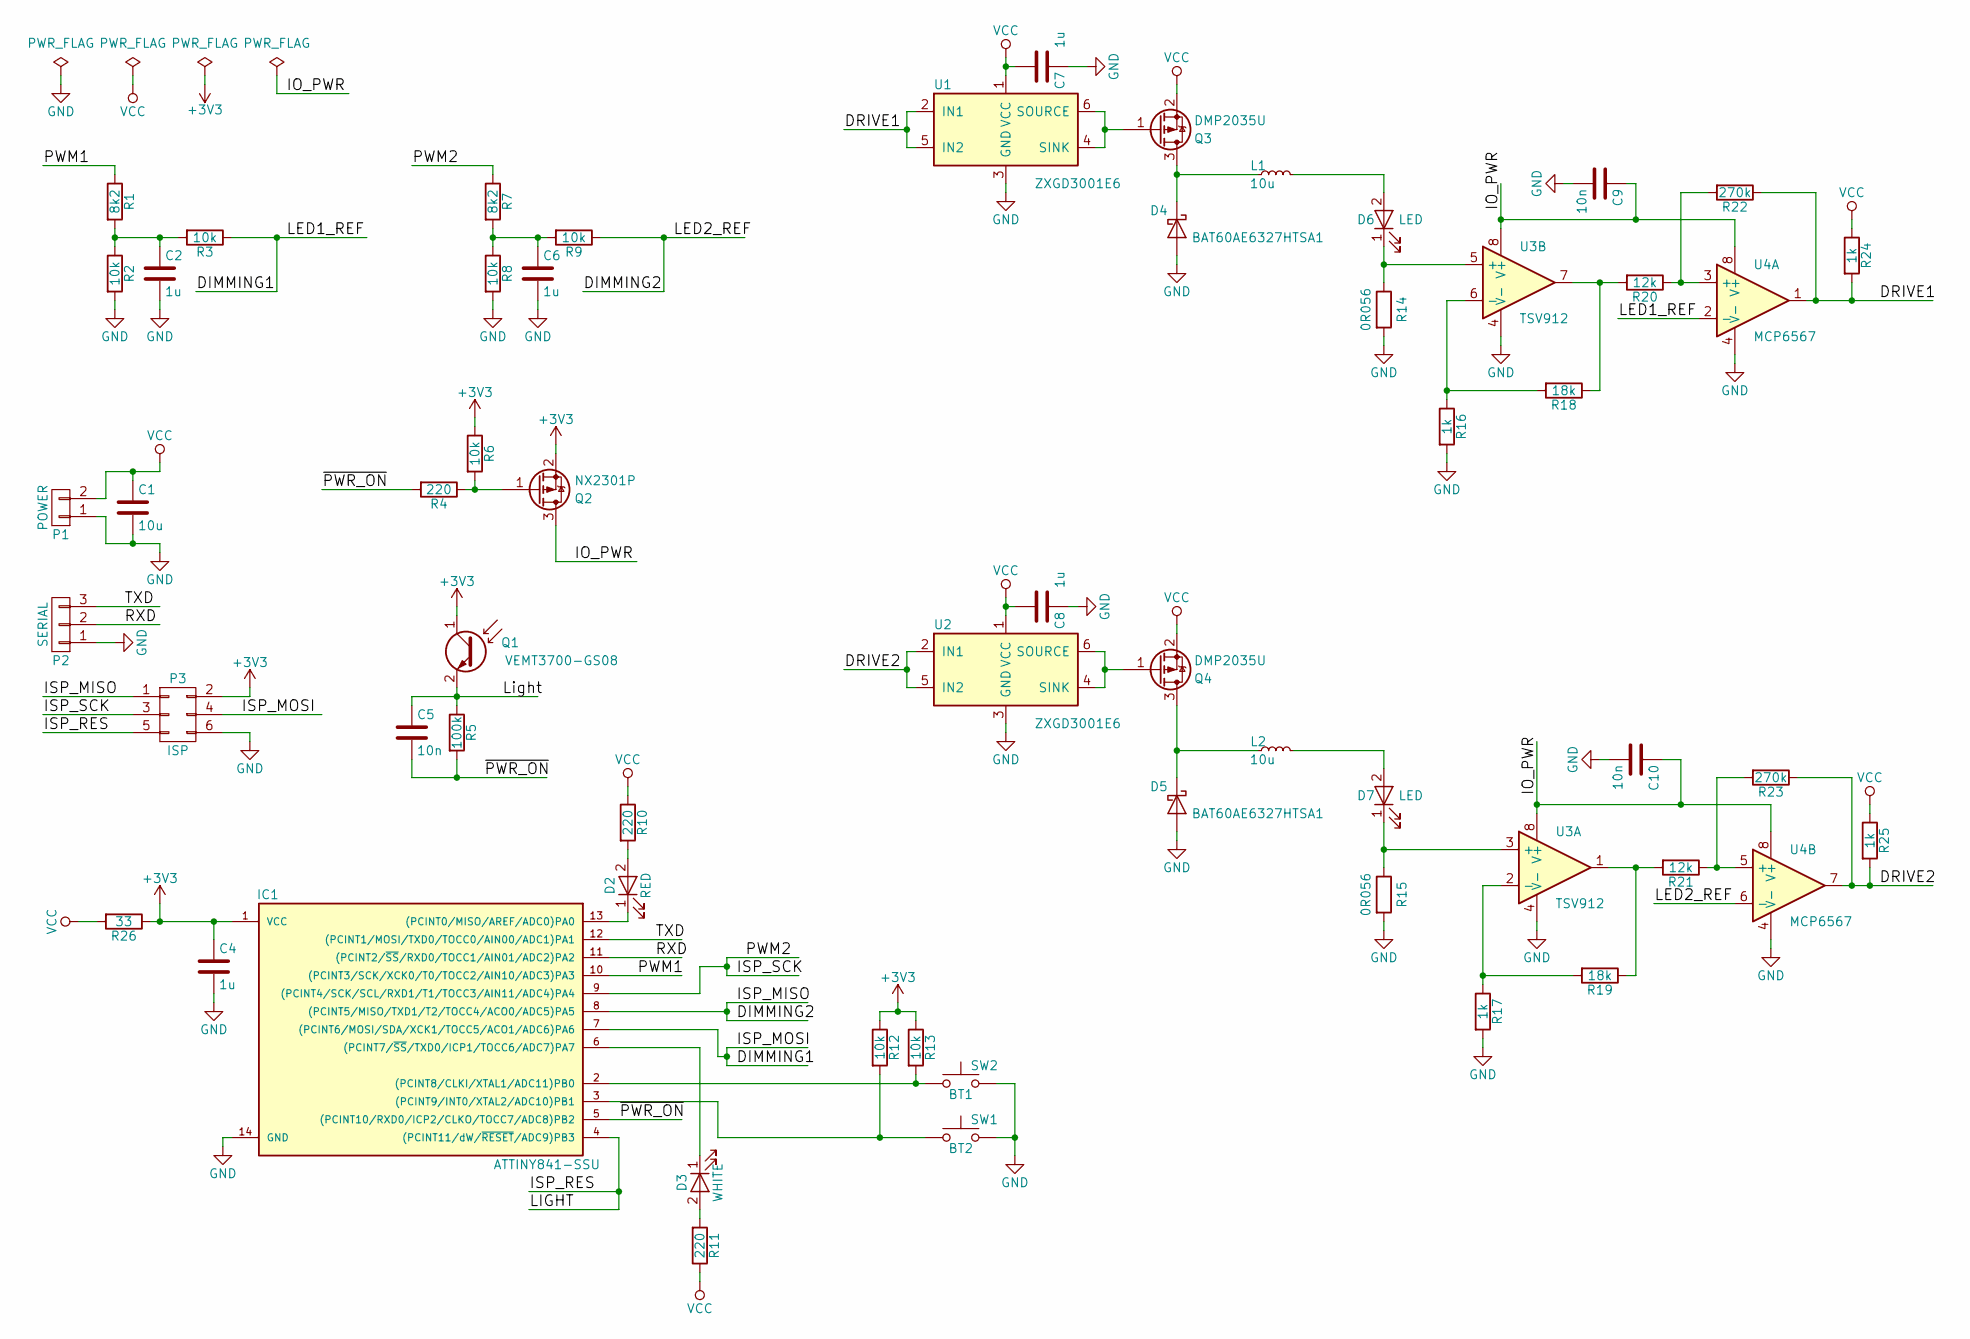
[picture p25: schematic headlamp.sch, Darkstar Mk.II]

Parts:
C1: 10u; C_0603
C2, C4, C6, C7, C8: 1u; C_0603
C5, C9, C10: 10n; C_0603
D2: RED; LED_PLCC-2
D3: WHITE; LED_PLCC-2
D4, D5: BAT60AE6327HTSA1; SOD-323
D6, D7: LED; Custom_Conn_2_Big
IC1: ATTINY841-SSU; SOIC-14_3.9x8.7mm_Pitch1.27mm
L1, L2: 10u; Inductor_Bourns-SRU8043
P1: POWER; Custom_Conn_2_Big
P2: SERIAL; GS3
P3: ISP; SOT-23-6
Q1: VEMT3700-GS08; LED_PLCC-2
Q2: NX2301P; SOT-23
Q3, Q4: DMP2035U; SOT-23
R1, R7: 8k2; R_0603
R2, R3, R6, R8, R9, R12, R13: 10k; R_0603
R4, R10, R11: 220; R_0603
R5: 100k; R_0603
R14, R15: 0R056; R_1206
R16, R17, R24, R25: 1k; R_0603
R18, R19: 18k; R_0603
R20, R21: 12k; R_0603
R22, R23: 270k; R_0603
R26: 33; R_0603
SW1: BT2; SW_SPST_FSMSM
SW2: BT1; SW_SPST_FSMSM
U1, U2: ZXGD3001E6; SOT-23-6
U3: TSV912; MSOP-8_3x3mm_Pitch0.65mm
U4: MCP6567; MSOP-8_3x3mm_Pitch0.65mm

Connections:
+3V3: C4.1, IC1.1 (VCC), P3.2, Q1.1 (C), Q2.2 (S), R6.1, R12.1, R13.1, R26.1
/DIMMING1: IC1.7 ((PCINT6/MOSI/SDA/XCK1/TOCC5/ACO1/ADC6)P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), P3.4, R3.1, U4.2 (-)
/DIMMING2: IC1.8 ((PCINT5/MISO/TXD1/T2/TOCC4/ACO0/ADC5)PA5), P3.1, R9.1, U4.6 (-)
/DRIVE1: R22.1, R24.2, U1.2 (IN1), U1.5 (IN2), U4.1
/DRIVE2: R23.1, R25.2, U2.2 (IN1), U2.5 (IN2), U4.7
/IO_PWR: C9.1, C10.1, Q2.3 (D), U3.8 (V+), U4.8 (V+)
/ISP_RES: C5.1, IC1.4 ((PCINT11/dW/~RESET~/ADC9)PB3), P3.5, Q1.2 (E), R5.1
/ISP_SCK: IC1.9 ((PCINT4/SCK/SCL/RXD1/T1/TOCC3/AIN11/ADC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), P3.3, R7.1
/PWM1: IC1.10 ((PCINT3/SCK/XCK0/T0/TOCC2/AIN10/ADC3)PA3), R1.1
/RXD: IC1.11 ((PCINT2/~SS~/RXD0/TOCC1/AIN01/ADC2)PA2), P2.2
/TXD: IC1.12 ((PCINT1/MOSI/TXD0/TOCC0/AIN00/ADC1)PA1), P2.3
/~PWR_ON: C5.2, IC1.5 ((PCINT10/RXD0/ICP2/CLKO/TOCC7/ADC8)PB2), R4.2, R5.2
GND: C1.2, C2.2, C4.2, C6.2, C7.1, C8.1, C9.2, C10.2, D4.2 (A), D5.2 (A), IC1.14 (GND), P1.1, P2.1, P3.6, R2.2, R8.2, R14.2, R15.2, R16.2, R17.2, SW1.2, SW2.2, U1.3 (GND), U2.3 (GND), U3.4 (V-), U4.4 (V-)
unnamed: C2.1, R1.2, R2.1, R3.2
unnamed: C6.1, R7.2, R8.1, R9.2
unnamed: D2.1 (K), IC1.13 ((PCINT0/MISO/AREF/ADC0)PA0)
unnamed: D2.2 (A), R10.2
unnamed: D3.1 (K), IC1.6 ((PCINT7/~SS~/TXD0/ICP1/TOCC6/ADC7)PA7)
unnamed: D3.2 (A), R11.2
unnamed: D4.1 (K), L1.1, Q3.3 (D)
unnamed: D5.1 (K), L2.1, Q4.3 (D)
unnamed: D6.1 (K), R14.1, U3.5 (+)
unnamed: D6.2 (A), L1.2
unnamed: D7.1 (K), R15.1, U3.3 (+)
unnamed: D7.2 (A), L2.2
unnamed: IC1.2 ((PCINT8/CLKI/XTAL1/ADC11)PB0), R13.2, SW2.1
unnamed: IC1.3 ((PCINT9/INT0/XTAL2/ADC10)PB1), R12.2, SW1.1
unnamed: Q2.1 (G), R4.1, R6.2
unnamed: Q3.1 (G), U1.4 (SINK), U1.6 (SOURCE)
unnamed: Q4.1 (G), U2.4 (SINK), U2.6 (SOURCE)
unnamed: R16.1, R18.2, U3.6 (-)
unnamed: R17.1, R19.2, U3.2 (-)
unnamed: R18.1, R20.2, U3.7
unnamed: R19.1, R21.2, U3.1
unnamed: R20.1, R22.2, U4.3 (+)
unnamed: R21.1, R23.2, U4.5 (+)
VCC: C1.1, C7.2, C8.2, P1.2, Q3.2 (S), Q4.2 (S), R10.1, R11.1, R24.1, R25.1, R26.2, U1.1 (VCC), U2.1 (VCC)

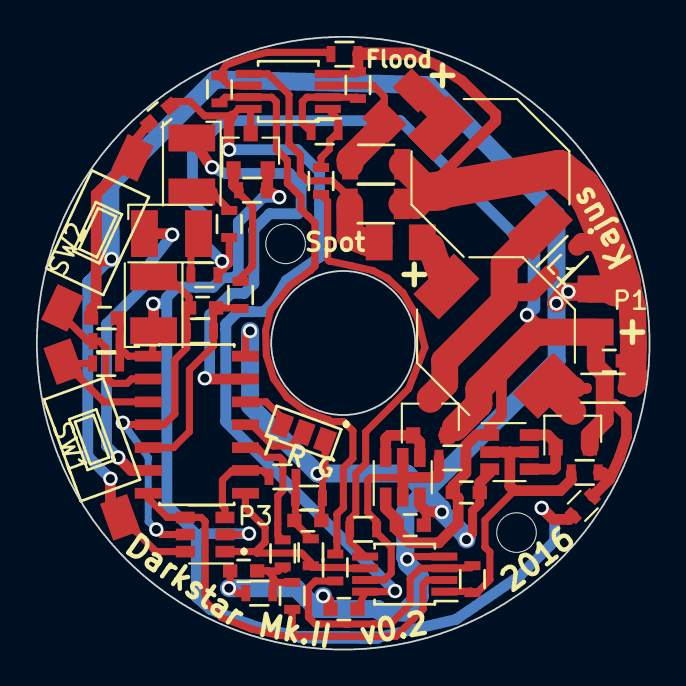
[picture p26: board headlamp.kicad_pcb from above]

Board: 2 copper layers, 34.0 x 34.0 mm, 57 parts (0 on the bottom side), 37 nets.

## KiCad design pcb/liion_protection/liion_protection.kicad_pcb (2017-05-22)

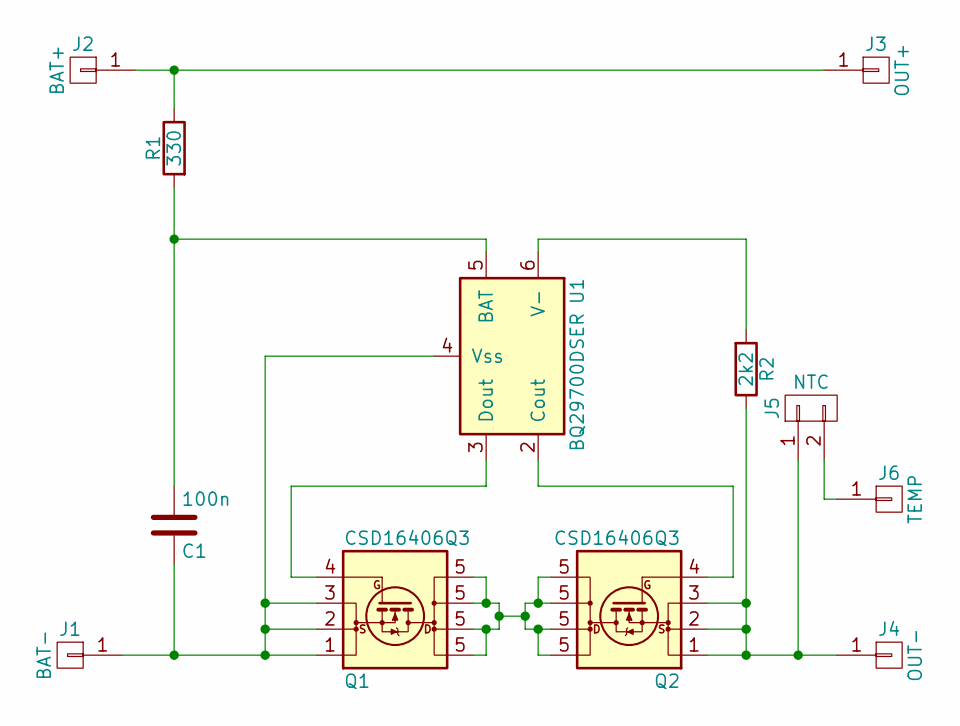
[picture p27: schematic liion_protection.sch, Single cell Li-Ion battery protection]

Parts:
C1: 100n; C_0603
J1: BAT-; 1Pin
J2: BAT+; 1Pin
J3: OUT+; 1Pin
J4: OUT-; 1Pin
J5: NTC; GS2
J6: TEMP; 1Pin
Q1, Q2: CSD16406Q3; VSON-8_3.3x3.3mm_Pitch0.65mm_NexFET
R1: 330; R_0603
R2: 2k2; R_0603
U1: BQ29700DSER; WSON6_1.5x1.5mm_Pitch0.5mm

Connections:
unnamed: C1.1, J1.1, Q1.1 (S), Q1.2 (S), Q1.3 (S), U1.4 (Vss)
unnamed: C1.2, R1.2, U1.5 (BAT)
unnamed: J2.1, J3.1, R1.1
unnamed: J4.1, J5.1, Q2.1 (S), Q2.2 (S), Q2.3 (S), R2.1
unnamed: J5.2, J6.1
unnamed: Q1.4 (G), U1.3 (Dout)
unnamed: Q1.5 (D), Q2.5 (D)
unnamed: Q2.4 (G), U1.2 (Cout)
unnamed: R2.2, U1.6 (V-)

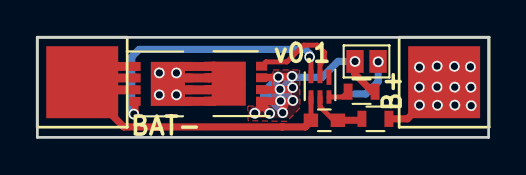
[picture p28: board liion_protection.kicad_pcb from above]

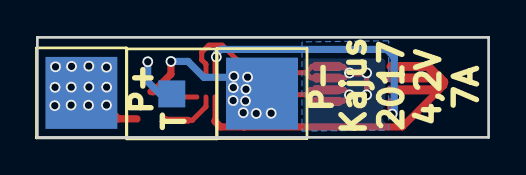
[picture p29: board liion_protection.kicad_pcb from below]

Board: 2 copper layers, 25.1 x 5.6 mm, 12 parts (3 on the bottom side), 9 nets.

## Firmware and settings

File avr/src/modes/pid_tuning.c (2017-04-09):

/*
 * pid tuning mode
 *
 * For license, see LICENSE.txt
 *
 * Jakub Kaderka 2017
 */

#include <inttypes.h>
#include <stdio.h>

#include "buttons.h"
#include "system.h"
#include "hal/uart.h"
#include "utils/pid.h"
#include "config.h"
#include "hal/adc.h"
#include "light.h"

#ifndef UART_ENABLED
	#error "UART_ENABLED not set"
#endif

uint8_t kp;
uint8_t ki;
uint8_t kd;

uint8_t enabled = 0;

struct s_pid pid;

#define LEVEL 50
#define I_MAX 8192

void init(void)
{
	kp = PID_KP;
	ki = PID_KI;
	kd = PID_KD;
	pid_init(&pid, kp, ki, kd);
	wdt_disable();
}

void loop(void)
{
	char c = 0;
	uint8_t res, adc;

	if (uart_check_rx() != 0)
		c = getchar();

	switch (c) {
		case 'w':
			kp = kp == 255 ? kp : kp+1;
			break;
		case 'q':
			kp = kp == 0 ? kp : kp-1;
			break;
		case 's':
			ki = ki == 255 ? ki : ki+1;
			break;
		case 'a':
			ki = ki == 0 ? ki : ki-1;
			break;
		case 'x':
			kd = kd == 255 ? kd : kd+1;
			break;
		case 'z':
			kd = kd == 0 ? kd : kd-1;
			break;
		case 'r':
			enabled = 1;
			break;
		case 'b':
			enabled = 0;
			break;

	}

	pid.kp = kp;
	pid.ki = ki;
	pid.kd = kd;
	pid.max_err = INT16_MAX / kp;
	pid.max_sum = I_MAX > INT16_MAX / ki ? INT16_MAX/ki : I_MAX;

	printf("\e[1;1H\e[2JKP: %d\n", kp);
	printf("KI: %d\n", ki);
	printf("KD: %d\n", kd);
	adc = adc_read8(PHOTOTRANS_ADC, AD_REF_1_1V);
	res = pid_get(&pid, LEVEL, adc);
	printf("adc: %d\n", adc);

	if (res < DEFAULT_DIM_CURRENT)
		res = DEFAULT_DIM_CURRENT;

	if (res > 150)
		res = 150;

	printf("res: %d\n", res);

	if (enabled)
		light_set_simple(LED_FLOOD, res, MODE_NORMAL);
	else
		light_set_simple(LED_FLOOD, 0, MODE_NORMAL);
}

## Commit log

2016-12-04 Rearranged schematics
    [headlamp.sch]
2016-12-10 Switched to open drain comparator
    [headlamp.sch]
2016-12-20 Added led driver code
2016-12-20 Added led pwm dimming
2016-12-20 Simple system timer added
2016-12-20 LEDs moved to hal layer
2016-12-22 Added button handling
2016-12-22 Buttons reading added
2016-12-22 Power off added
2016-12-23 PWM dimming must be slower
2016-12-28 Board added
    [headlamp.kicad_pcb, headlamp.sch]
2016-12-31 Added gerber files
    [headlamp.kicad_pcb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]
2016-12-31 Added leds_enabled check function
2016-12-31 Disable leds when going to sleep
2016-12-31 ADC voltage returned in mV
2017-01-03 Added support for dropin on in supply rail diode protection aka peak detector
2017-01-03 Interrupts setting
2017-01-03 Added power off handling
2017-01-03 Fixed button detection
2017-01-13 Added millis to system library
2017-01-23 Fixed binary safe uart
2017-01-29 Fixed small LEDs connections
2017-01-29 Fixed PWM incorrect register setting
2017-01-29 Updated port mapping to match board
2017-01-29 Final schematic values, pcb
    [headlamp.kicad_pcb, headlamp.sch]
2017-01-29 Fixed millis timing, attiny not setting overflow flag on match overflow
2017-01-30 Turn off pwm output when brightness == 0
2017-01-30 leds enable/disable simplified
2017-02-03 Fixed uart
2017-02-03 Fixed adc pin setting and conversion result
2017-02-03 Reduced adc frequency for improved accuracy
2017-02-03 Updated defines for adc api
2017-02-03 fixed system voltage reading when diode is used
2017-02-03 Turn off pwm when battery dead or body overheated
2017-02-11 Ignore limits for small leds
2017-02-11 Slowed dimming PWM - the output was not stable over 150Hz
2017-02-16 Updated low voltage levels
2017-03-09 added option to disable uart
2017-03-09 Added button press detection after powerup
2017-03-09 Fixed hole between short and long press
2017-03-11 Fixed PWM settings for led
2017-03-11 Updated capacitors values
    [headlamp.kicad_pcb, headlamp.sch]
2017-03-11 fixed modes switching in simple mode
2017-03-11 fixed level switching
2017-03-17 Fixed button reading on startup
2017-03-18 Updated phototransistor wiring due to error on board
2017-03-19 Added pid light regulation
2017-03-21 Read temperature and voltage only once per cycle
2017-03-21 Fixed no voltage report on full
2017-03-22 Merged reporting and rating voltage levels
2017-04-09 Fixed PID calculations
2017-04-09 Added start/stop option to pid tuner
2017-04-09 Error when UART_ENABLED not set in pid tuner
    [pid_tuning.c]
2017-04-09 Added fuse programming to makefile
2017-04-15 added one side limits for voltage
2017-04-15 Avoid setting all leds off in programming
2017-04-15 Blink with same led for all actions
2017-04-23 Replaced diode by resistor - was causing rising mcu VCC from spikes on power lines
    [headlamp.kicad_pcb, headlamp.sch]
2017-04-25 Added stls for battery box
    [battery_box.stl, box_lid.stl, knob.stl]
2017-05-08 Added BOM
    [BOM.csv]
2017-05-12 Fixed low voltage reporting
2017-05-12 Average system voltage
2017-05-12 Updated battery limiting
2017-05-12 Initial drawings
    [body.dxf, bushing.dxf, bushing_insert.dxf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]
2017-05-19 Fixed limits for negative temperature
2017-05-21 Added drawings
    [body.dxf, bushing.dxf, bushing_insert.dxf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]
2017-05-22 Added liion protection pcb
    [BOM.csv, headlamp.kicad_pcb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]
2017-05-22 Removed panelized headlamp
    [headlamp.kicad_pcb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]
2017-05-22 Remove voltage spikes building up
    [headlamp.kicad_pcb, headlamp.sch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]
2017-05-22 Updated BOM
2017-05-22 Added pdf schematics
2017-08-16 Replaced phototransistor by LED
2017-08-16 Refractored battery limits
2017-09-18 Turn of blinking immediately when powered off
2017-09-18 Fixed flags for programming fuses
2017-09-24 Match RED/WHITE led to pcb description
2017-09-24 Fixed central rod dimensions
2017-11-19 Testing heat and impact resistance
2017-12-10 Added better seal to battery box
    [battery_box.stl, box_lid.stl]
2017-12-20 Added missing o-ring to BOM
2017-12-21 Moved cutout little higher
    [battery_box.stl]
2018-03-19 Fixed hole size
2018-03-28 Fixed hole position
